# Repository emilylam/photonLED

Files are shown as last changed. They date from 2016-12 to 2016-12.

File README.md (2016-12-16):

# photonLED

Breakout board for MC-E LED for the Photon.

Repository includes some barebones example code.

LED wiring: <br>
white -- A5 <br>
red -- A4 <br>
green -- WKP <br>
blue -- TX <br>

There is also a color sensor, TCS34725. It's wired up to the I2C bus. Just use the Adafruit library.

Power: <br>
5V on USB, 5V on terminal block, or 7-12V on DC jack. Total current consumption is around 900mA. Make sure power source can source 1A.

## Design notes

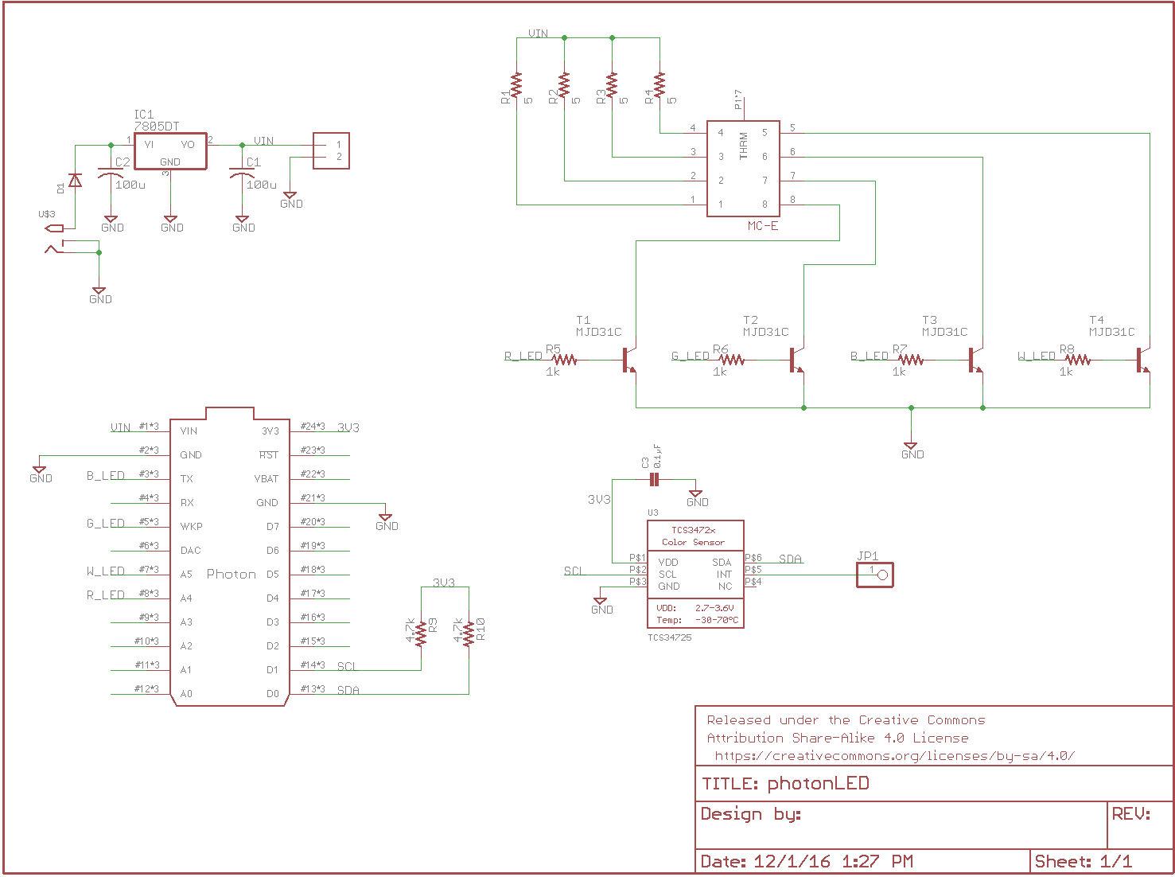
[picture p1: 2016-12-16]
photonLED_sch.png

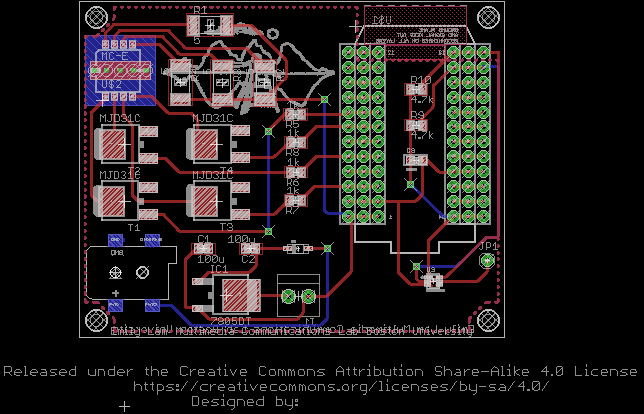
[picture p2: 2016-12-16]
photonLED_brd.png

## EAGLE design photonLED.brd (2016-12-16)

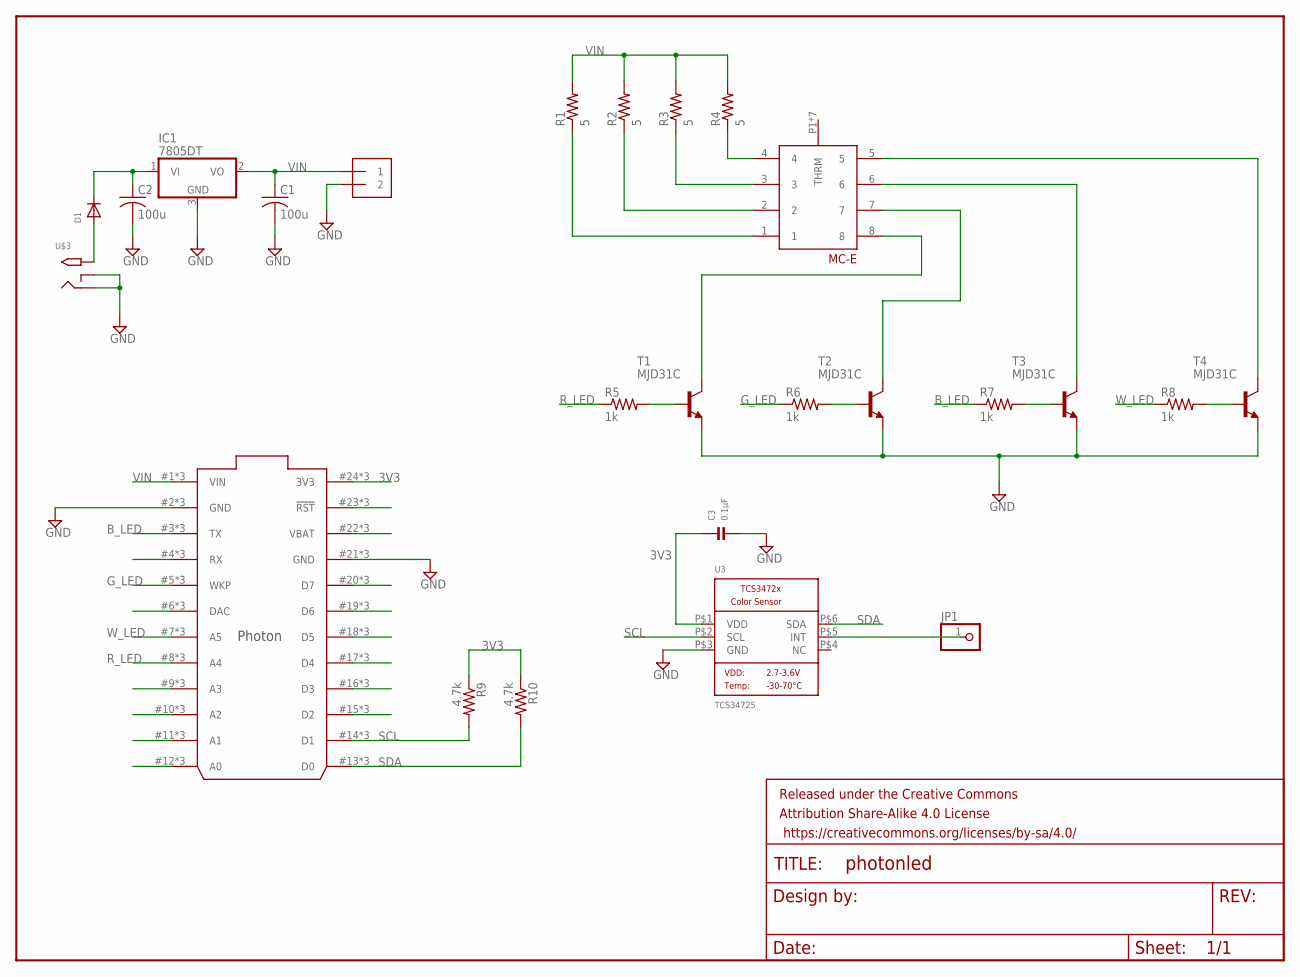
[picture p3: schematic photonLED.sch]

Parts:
C1, C2: 100u; C0805
C3: 0.1µF; _0805
D1: DIODESOD-123; SOD-123
FRAME1: FRAME-LETTER; CREATIVE_COMMONS
IC1: 7805DT; TO252
J1: 3.5MM Screw Term; 1X2-3.5MM
JP1: PINHD-1X1; 1X01
R1, R2, R3, R4: 5; R2512
R5, R6, R7, R8: 1k; R0805
R9, R10: 4.7k; R0805
T1, T2, T3, T4: MJD31C; DPAK
U3: TCS34725; TCS3472_FN6
U$1: PHOTON_WITH_STACKABLE_HEADERS; PHOTON_STACKABLE
U$2: MC-E
U$3: 2.1MMJACKSMT; DCJACK_2MM_SMT

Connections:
3V3: C3.1, R9.1, R10.1, U3.P$1 (VDD), U$1.24 (3V3), U$1.#24 (3V3), U$1.@24 (3V3)
B_LED: R7.1, U$1.3 (TX), U$1.#3 (TX), U$1.@3 (TX)
GND: C1.2, C2.2, C3.2, IC1.3 (GND), J1.2, T1.3 (E), T2.3 (E), T3.3 (E), T4.3 (E), U3.P$3 (GND), U$1.2 (GND), U$1.21 (GND), U$1.#2 (GND), U$1.#21 (GND), U$1.@2 (GND), U$1.@21 (GND), U$3.GND (RING), U$3.GNDBREAK (RING_SW)
G_LED: R6.1, U$1.5 (WKP), U$1.#5 (WKP), U$1.@5 (WKP)
unnamed: R4.1, U$2.4
unnamed: R3.1, U$2.3
unnamed: R2.1, U$2.2
unnamed: R1.1, U$2.1
unnamed: T1.4 (C), U$2.8
unnamed: R6.2, T2.1 (B)
unnamed: T2.4 (C), U$2.7
unnamed: T3.4 (C), U$2.6
unnamed: D1.A, U$3.PWR2 (TIP)
unnamed: C2.1, D1.C, IC1.1 (VI)
unnamed: JP1.1, U3.P$5 (INT)
unnamed: U$1.10 (A2), U$1.#10 (A2), U$1.@10 (A2)
unnamed: U$1.6 (DAC), U$1.#6 (DAC), U$1.@6 (DAC)
unnamed: U$1.4 (RX), U$1.#4 (RX), U$1.@4 (RX)
unnamed: U$1.9 (A3), U$1.#9 (A3), U$1.@9 (A3)
unnamed: T4.4 (C), U$2.5
unnamed: U$1.11 (A1), U$1.#11 (A1), U$1.@11 (A1)
unnamed: U$1.12 (A0), U$1.#12 (A0), U$1.@12 (A0)
unnamed: U$1.23 (!RST), U$1.#23 (!RST), U$1.@23 (!RST)
unnamed: U$1.22 (VBAT), U$1.#22 (VBAT), U$1.@22 (VBAT)
unnamed: U$1.20 (D7), U$1.#20 (D7), U$1.@20 (D7)
unnamed: U$1.19 (D6), U$1.#19 (D6), U$1.@19 (D6)
unnamed: U$1.18 (D5), U$1.#18 (D5), U$1.@18 (D5)
unnamed: U$1.17 (D4), U$1.#17 (D4), U$1.@17 (D4)
unnamed: U$1.16 (D3), U$1.#16 (D3), U$1.@16 (D3)
unnamed: U$1.15 (D2), U$1.#15 (D2), U$1.@15 (D2)
unnamed: R5.2, T1.1 (B)
unnamed: R7.2, T3.1 (B)
unnamed: R8.2, T4.1 (B)
R_LED: R5.1, U$1.8 (A4), U$1.#8 (A4), U$1.@8 (A4)
SCL: R9.2, U3.P$2 (SCL), U$1.14 (D1), U$1.#14 (D1), U$1.@14 (D1)
SDA: R10.2, U3.P$6 (SDA), U$1.13 (D0), U$1.#13 (D0), U$1.@13 (D0)
VIN: C1.1, IC1.2 (VO), J1.1, R1.2, R2.2, R3.2, R4.2, U$1.1 (VIN), U$1.#1 (VIN), U$1.@1 (VIN)
W_LED: R8.1, U$1.7 (A5), U$1.#7 (A5), U$1.@7 (A5)

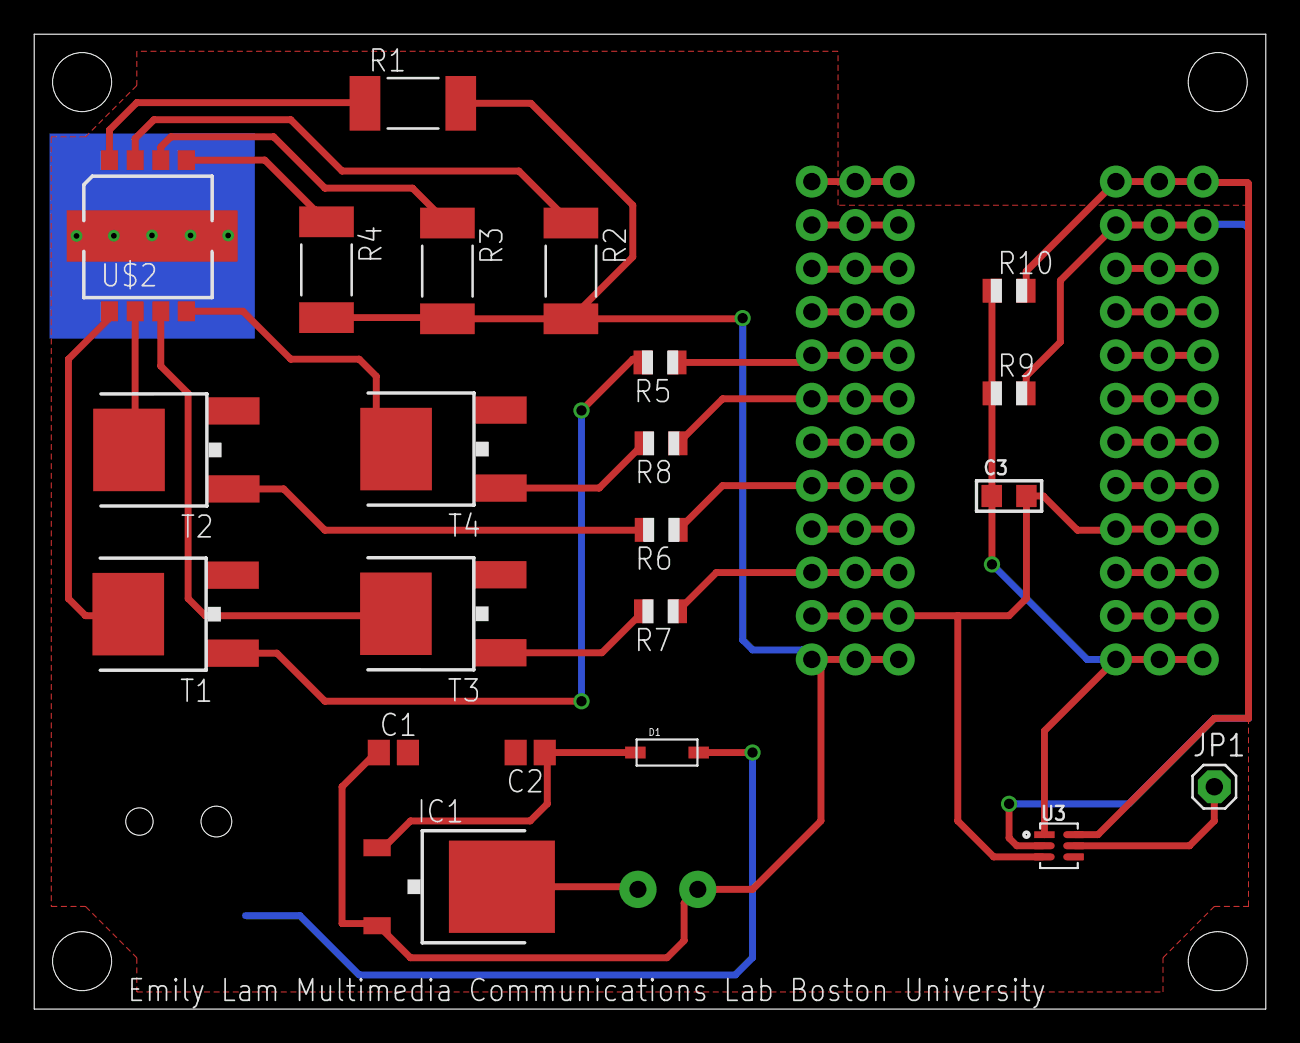
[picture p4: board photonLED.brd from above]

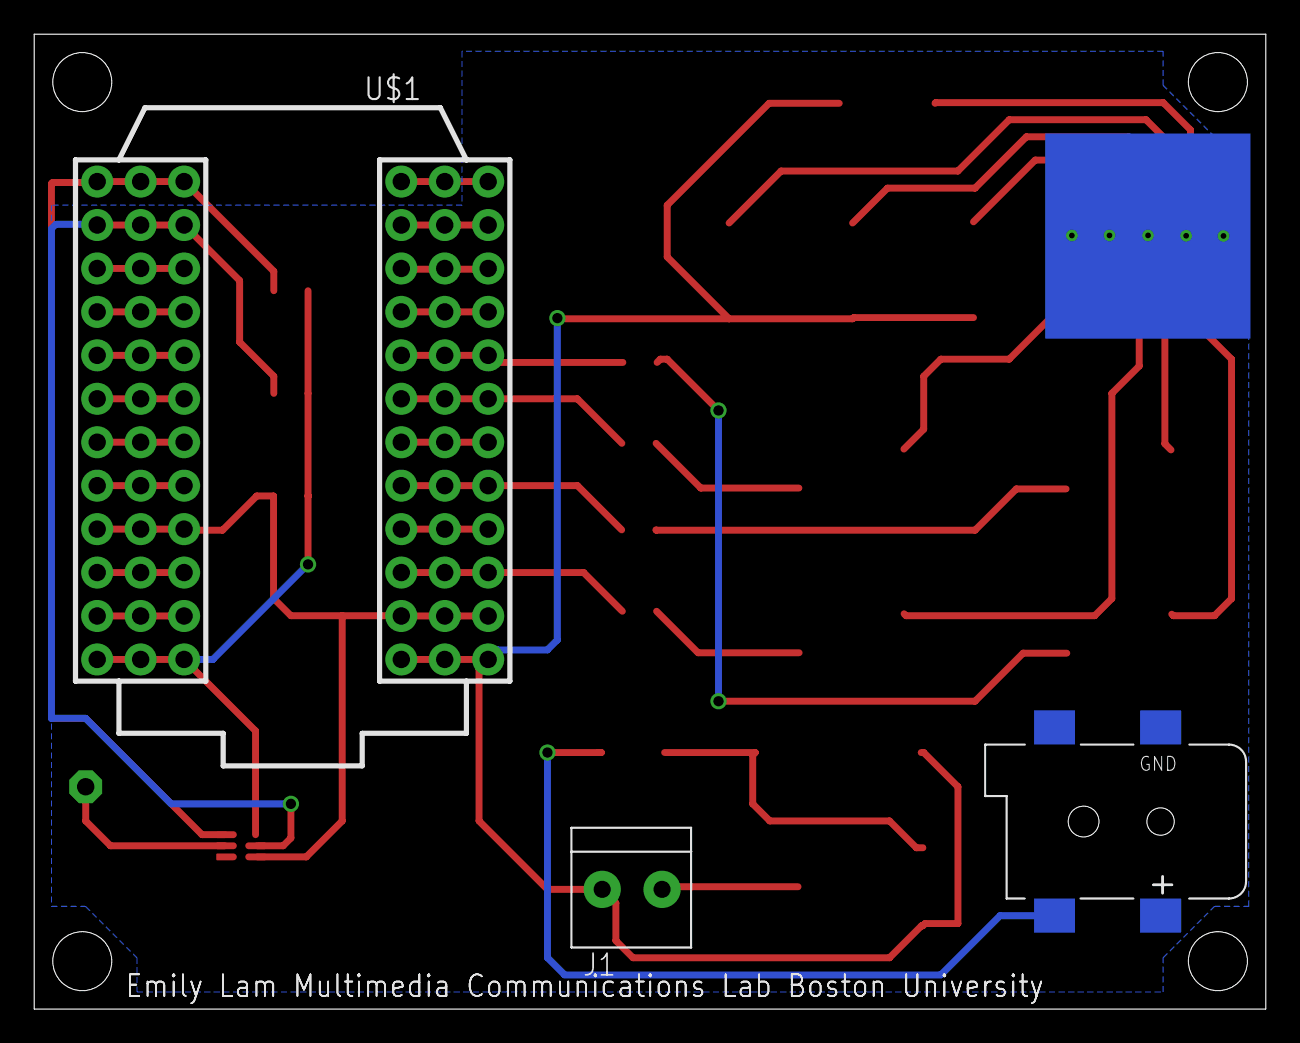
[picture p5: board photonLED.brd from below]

Board: 2 copper layers, 72.0 x 57.0 mm, 26 parts (3 on the bottom side), 38 nets.

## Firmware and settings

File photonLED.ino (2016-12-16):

/*
Basic test code for the CREE MC-E LED

Emily Lam, November 2016
*/

// Does not connect to WiFi
SYSTEM_MODE(SEMI_AUTOMATIC);

// Declare pins and frequency
int white = A5;
int red = A4;
int green = WKP;
int blue = TX;
int freq = 1000;

// Setup
void setup() {
  pinMode(red, OUTPUT);
  pinMode(green, OUTPUT);
  pinMode(blue, OUTPUT);
  pinMode(white, OUTPUT);
}

// Flash LEDs one at a time
void loop() {
  analogWrite(white, 0, freq);
  analogWrite(red, 128, freq);
  delay(500);
  analogWrite(red, 0, freq);
  analogWrite(blue, 128, freq);
  delay(500);
  analogWrite(blue, 0, freq);
  analogWrite(green, 128, freq);
  delay(500);
  analogWrite(green, 0, freq);
  analogWrite(white, 128, freq);
  delay(500);


}

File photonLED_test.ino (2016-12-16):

// SYSTEM_MODE(SEMI_AUTOMATIC);

int ledPin1 = A5;
int ledPin2 = A4;
int ledPin3 = RX;
int ledPin4 = TX;
int freq = 1000;
int flag = 0;

void setup()
{
  pinMode(ledPin1, OUTPUT);
  pinMode(ledPin2, OUTPUT);
  pinMode(ledPin3, OUTPUT);
  pinMode(ledPin4, OUTPUT);

  Particle.function("led",ledToggle);

  digitalWrite(ledPin1, HIGH);
  digitalWrite(ledPin2, HIGH);
  digitalWrite(ledPin3, HIGH);
  digitalWrite(ledPin4, HIGH);
}

void loop()
{
  if (flag == 1) {

    pinMode(ledPin1, OUTPUT);
    pinMode(ledPin2, OUTPUT);
    pinMode(ledPin3, OUTPUT);
    pinMode(ledPin4, OUTPUT);

    analogWrite(ledPin1, 128, freq);
    analogWrite(ledPin2, 128, freq);
    analogWrite(ledPin2, 128, freq);
    analogWrite(ledPin2, 128, freq);
  }
  /*pinSetFast(ledPin3);           // set the LED on
  delayMicroseconds(20);
  pinResetFast(ledPin3);       // set the LED off
  delayMicroseconds(40);
  pinSetFast(ledPin3);
  delayMicroseconds(40);
  pinResetFast(ledPin3);
  delayMicroseconds(60);*/
  //analogWrite(ledPin4,128,1000);

  else if (flag == 0) {

    pinMode(ledPin1, INPUT);
    pinMode(ledPin2, INPUT);
    pinMode(ledPin3, INPUT);
    pinMode(ledPin4, INPUT);

  }


}

int ledToggle(String command) {

    if (command=="on") {
        flag = 1;
        return 1;
    }
    else if (command=="off") {
        flag = 0;
        return 0;
    }
    else {
        return -1;
    }
}

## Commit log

2016-10-24 draft broad
    [photonLED.brd, photonLED.sch]
2016-10-24 added voltage regulator, DC terminals, all on one side.
    [photonLED.brd, photonLED.sch]
2016-10-26 added color sensor, mounting holes, ground planes, etc.
    [photonLED.brd, photonLED.sch]
2016-10-28 final board layout
    [photonLED.brd, photonLED.sch]
2016-12-16 final board
    [photonLED.brd, photonLED.sch]

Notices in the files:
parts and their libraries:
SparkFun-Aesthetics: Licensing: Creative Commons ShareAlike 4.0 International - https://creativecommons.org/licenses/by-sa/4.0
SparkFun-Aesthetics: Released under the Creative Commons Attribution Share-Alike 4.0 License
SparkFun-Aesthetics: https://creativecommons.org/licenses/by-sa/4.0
